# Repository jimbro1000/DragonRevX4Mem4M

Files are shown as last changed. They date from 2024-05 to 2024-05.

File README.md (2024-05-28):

# Dragon 256 rev X4 Plus Memory Card #

This repository contains the hardware design
for a heavily revised Dragon 32 computer
memory board.

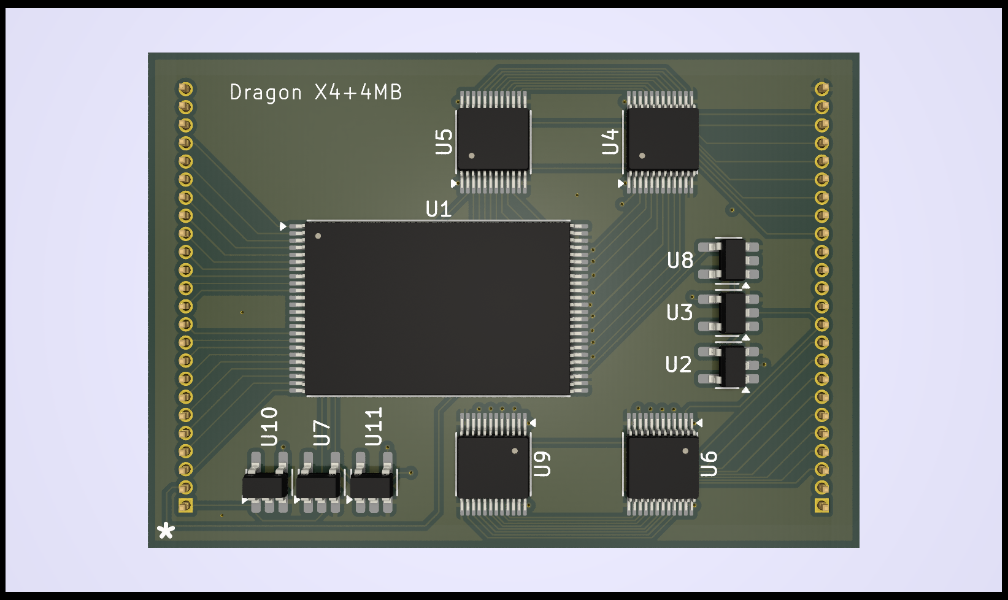
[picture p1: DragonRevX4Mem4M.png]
Render of Dragon Memory PCB


The design is most definitely experimental
and absolutely unproven

## Design ##

The board replaces the onboard memory
configuration used in early rev X4 PCBs

The bus connection supports a hypothetical
16MB but this is not currently practical

Even with 4MB on this card that main board
only contains logic to address 1MB but will
be expanded to control the full 4MB ASAP.

The remaining 12MB is intended for expansion
slots.

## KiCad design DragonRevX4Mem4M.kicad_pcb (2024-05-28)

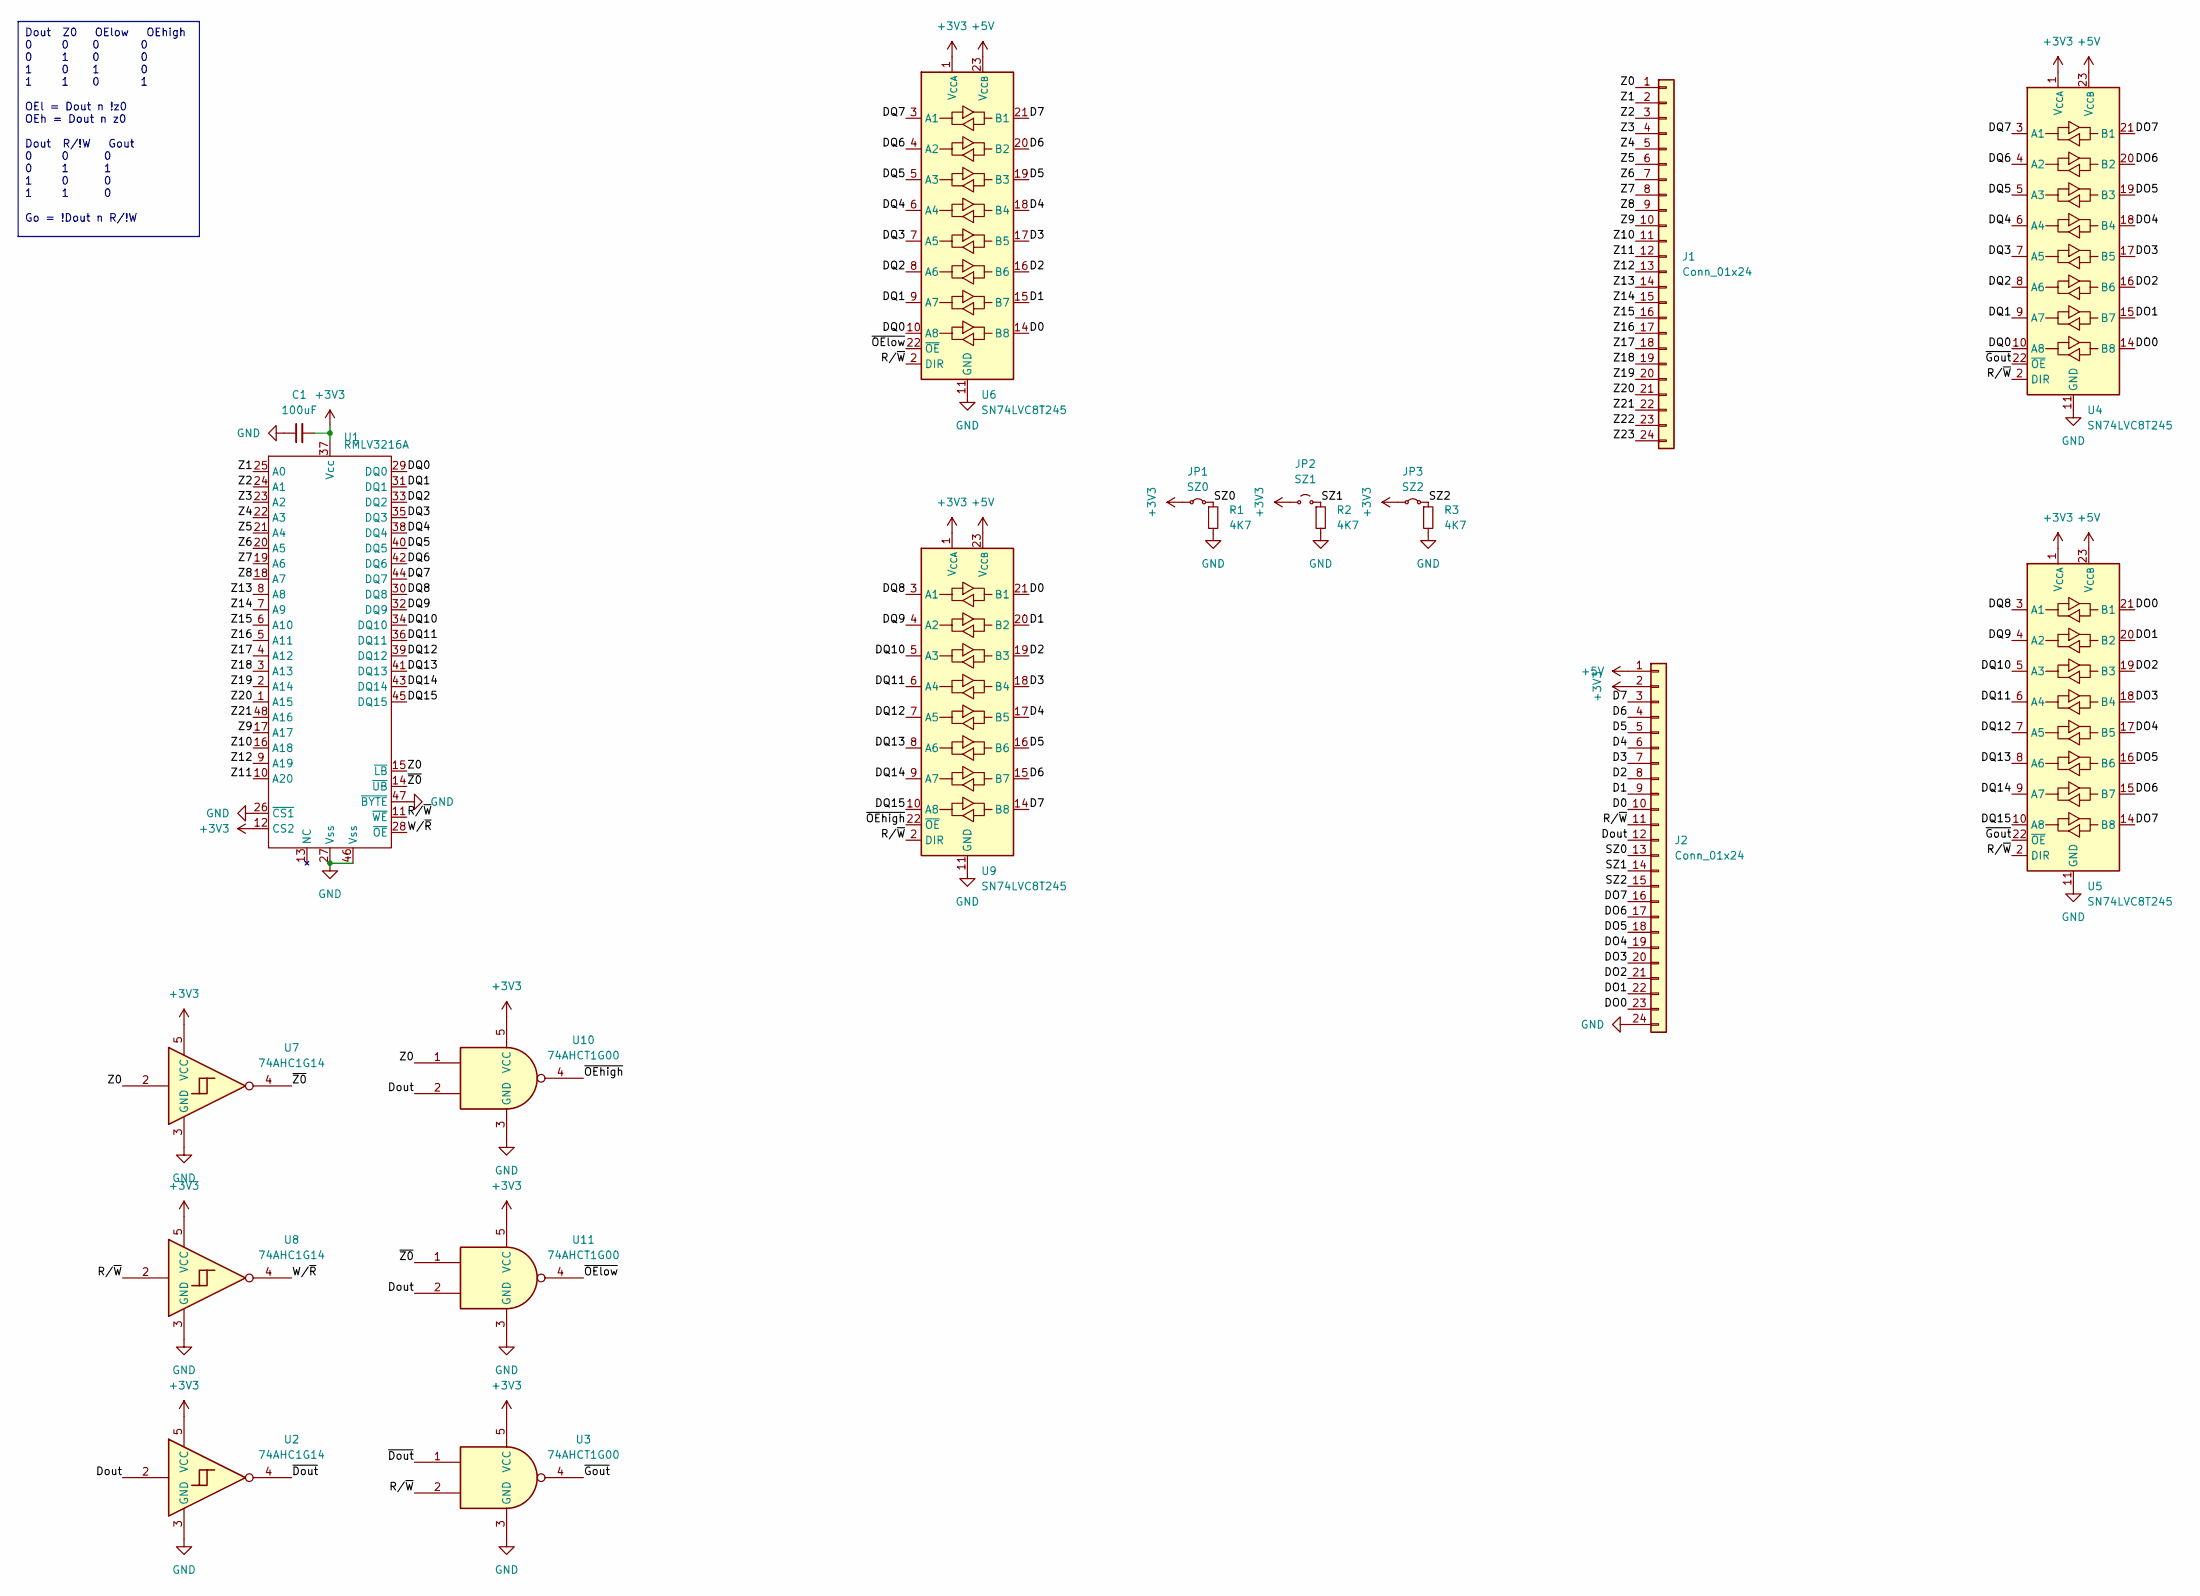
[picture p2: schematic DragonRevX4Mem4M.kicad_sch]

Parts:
C1: 100uF; C_0805_2012Metric
J1, J2: Conn_01x24; PinHeader_1x24_P1.27mm_Vertical
JP1: SZ0; SolderJumper-2_P1.3mm_Bridged_Pad1.0x1.5mm
JP2: SZ1; SolderJumper-2_P1.3mm_Open_Pad1.0x1.5mm
JP3: SZ2; SolderJumper-2_P1.3mm_Bridged_Pad1.0x1.5mm
R1, R2, R3: 4K7; C_0603_1608Metric
U1: RMLV3216A; TSOP-I-48_18.4x12mm_P0.5mm; DigiKey RMLV3216AGSA-5S2#AA0-ND
U2, U7, U8: 74AHC1G14; SOT-23-5_HandSoldering; DigiKey 296-1112-1-ND
U3, U10, U11: 74AHCT1G00; SOT-23-5_HandSoldering; DigiKey 296-1111-1-ND
U4, U5, U6, U9: SN74LVC8T245; TSSOP-24_4.4x5mm_P0.4mm; DigiKey 1727-4417-1-ND

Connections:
+3V3: C1.2, J2.2, JP1.1 (A), JP2.1 (A), JP3.1 (A), U1.12 (CS2), U1.37 (Vcc), U2.5 (VCC), U3.5 (VCC), U4.1 (V_{CCA}), U5.1 (V_{CCA}), U6.1 (V_{CCA}), U7.5 (VCC), U8.5 (VCC), U9.1 (V_{CCA}), U10.5 (VCC), U11.5 (VCC)
+5V: J2.1, U4.23 (V_{CCB}), U4.24 (V_{CCB}), U5.23 (V_{CCB}), U5.24 (V_{CCB}), U6.23 (V_{CCB}), U6.24 (V_{CCB}), U9.23 (V_{CCB}), U9.24 (V_{CCB})
/D0: J2.10, U6.14 (B8), U9.21 (B1)
/D1: J2.9, U6.15 (B7), U9.20 (B2)
/D2: J2.8, U6.16 (B6), U9.19 (B3)
/D3: J2.7, U6.17 (B5), U9.18 (B4)
/D4: J2.6, U6.18 (B4), U9.17 (B5)
/D5: J2.5, U6.19 (B3), U9.16 (B6)
/D6: J2.4, U6.20 (B2), U9.15 (B7)
/D7: J2.3, U6.21 (B1), U9.14 (B8)
/DO0: J2.23, U4.14 (B8), U5.21 (B1)
/DO1: J2.22, U4.15 (B7), U5.20 (B2)
/DO2: J2.21, U4.16 (B6), U5.19 (B3)
/DO3: J2.20, U4.17 (B5), U5.18 (B4)
/DO4: J2.19, U4.18 (B4), U5.17 (B5)
/DO5: J2.18, U4.19 (B3), U5.16 (B6)
/DO6: J2.17, U4.20 (B2), U5.15 (B7)
/DO7: J2.16, U4.21 (B1), U5.14 (B8)
/DQ0: U1.29 (DQ0), U4.10 (A8), U6.10 (A8)
/DQ1: U1.31 (DQ1), U4.9 (A7), U6.9 (A7)
/DQ2: U1.33 (DQ2), U4.8 (A6), U6.8 (A6)
/DQ3: U1.35 (DQ3), U4.7 (A5), U6.7 (A5)
/DQ4: U1.38 (DQ4), U4.6 (A4), U6.6 (A4)
/DQ5: U1.40 (DQ5), U4.5 (A3), U6.5 (A3)
/DQ6: U1.42 (DQ6), U4.4 (A2), U6.4 (A2)
/DQ7: U1.44 (DQ7), U4.3 (A1), U6.3 (A1)
/DQ8: U1.30 (DQ8), U5.3 (A1), U9.3 (A1)
/DQ9: U1.32 (DQ9), U5.4 (A2), U9.4 (A2)
/DQ10: U1.34 (DQ10), U5.5 (A3), U9.5 (A3)
/DQ11: U1.36 (DQ11), U5.6 (A4), U9.6 (A4)
/DQ12: U1.39 (DQ12), U5.7 (A5), U9.7 (A5)
/DQ13: U1.41 (DQ13), U5.8 (A6), U9.8 (A6)
/DQ14: U1.43 (DQ14), U5.9 (A7), U9.9 (A7)
/DQ15: U1.45 (DQ15), U5.10 (A8), U9.10 (A8)
/Dout: J2.12, U2.2, U10.2, U11.2
/R/~W: J2.11, U1.11 (~WE), U3.2, U4.2 (DIR), U5.2 (DIR), U6.2 (DIR), U8.2, U9.2 (DIR)
/SZ0: J2.13, JP1.2 (B), R1.1
/SZ1: J2.14, JP2.2 (B), R2.1
/SZ2: J2.15, JP3.2 (B), R3.1
/W/~R: U1.28 (~OE), U8.4
/Z0: J1.1, U1.15 (~LB), U7.2, U10.1
/Z1: J1.2, U1.25 (A0)
/Z2: J1.3, U1.24 (A1)
/Z3: J1.4, U1.23 (A2)
/Z4: J1.5, U1.22 (A3)
/Z5: J1.6, U1.21 (A4)
/Z6: J1.7, U1.20 (A5)
/Z7: J1.8, U1.19 (A6)
/Z8: J1.9, U1.18 (A7)
/Z9: J1.10, U1.17 (A17)
/Z10: J1.11, U1.16 (A18)
/Z11: J1.12, U1.10 (A20)
/Z12: J1.13, U1.9 (A19)
/Z13: J1.14, U1.8 (A8)
/Z14: J1.15, U1.7 (A9)
/Z15: J1.16, U1.6 (A10)
/Z16: J1.17, U1.5 (A11)
/Z17: J1.18, U1.4 (A12)
/Z18: J1.19, U1.3 (A13)
/Z19: J1.20, U1.2 (A14)
/Z20: J1.21, U1.1 (A15)
/Z21: J1.22, U1.48 (A16)
/Z22: J1.23
/Z23: J1.24
/~Dout: U2.4, U3.1
/~Gout: U3.4, U4.22 (~OE), U5.22 (~OE)
/~OEhigh: U9.22 (~OE), U10.4
/~OElow: U6.22 (~OE), U11.4
/~Z0: U1.14 (~UB), U7.4, U11.1
GND: C1.1, J2.24, R1.2, R2.2, R3.2, U1.26 (~CS1), U1.27 (Vss), U1.46 (Vss), U1.47 (~BYTE), U2.3 (GND), U3.3 (GND), U4.11 (GND), U4.12 (GND), U4.13 (GND), U5.11 (GND), U5.12 (GND), U5.13 (GND), U6.11 (GND), U6.12 (GND), U6.13 (GND), U7.3 (GND), U8.3 (GND), U9.11 (GND), U9.12 (GND), U9.13 (GND), U10.3 (GND), U11.3 (GND)

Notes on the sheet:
Dout Z0 OElow OEhigh 0 0 0 0 0 1 0 0 1 0 1 0 1 1 0 1 OEl = Dout n !z0 OEh = Dout n z0 Dout R/!W Gout 0 0 0 0 1 1 1 0 0 1 1 0 Go = !Dout n R/!W

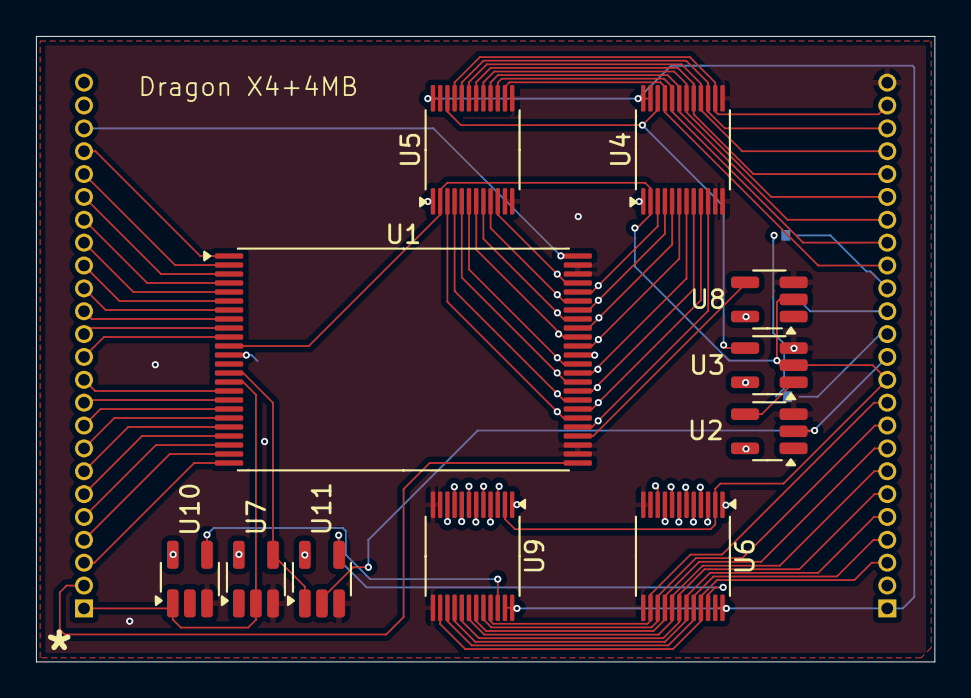
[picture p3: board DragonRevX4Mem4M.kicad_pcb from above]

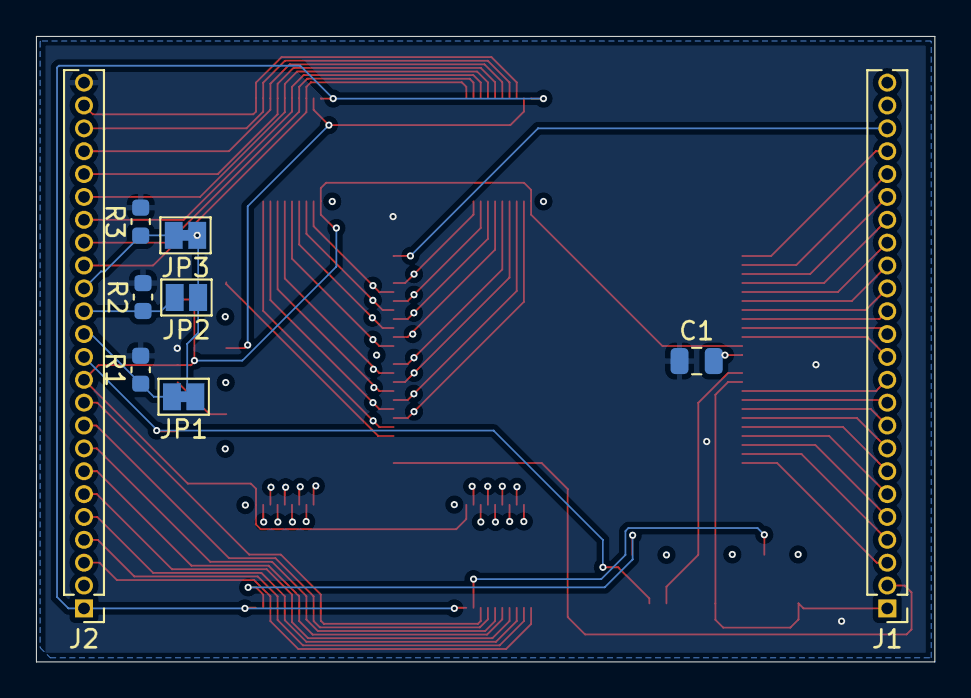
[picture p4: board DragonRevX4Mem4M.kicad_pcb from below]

Board: 4 copper layers, 49.9 x 34.7 mm, 20 parts (9 on the bottom side), 68 nets.
